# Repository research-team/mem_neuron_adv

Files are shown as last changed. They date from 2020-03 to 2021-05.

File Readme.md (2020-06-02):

Memristive neuron with selectable weights

[Link to a schematic viewer](https://www.altium.com/viewer/)

Weighted spiking neuron idea:
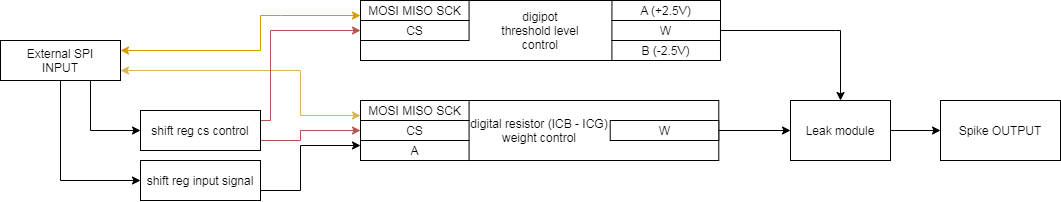
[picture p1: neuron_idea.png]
Basic idea


Last version spiking neuron schema: 
schema

Last version of spiking neuron board: 

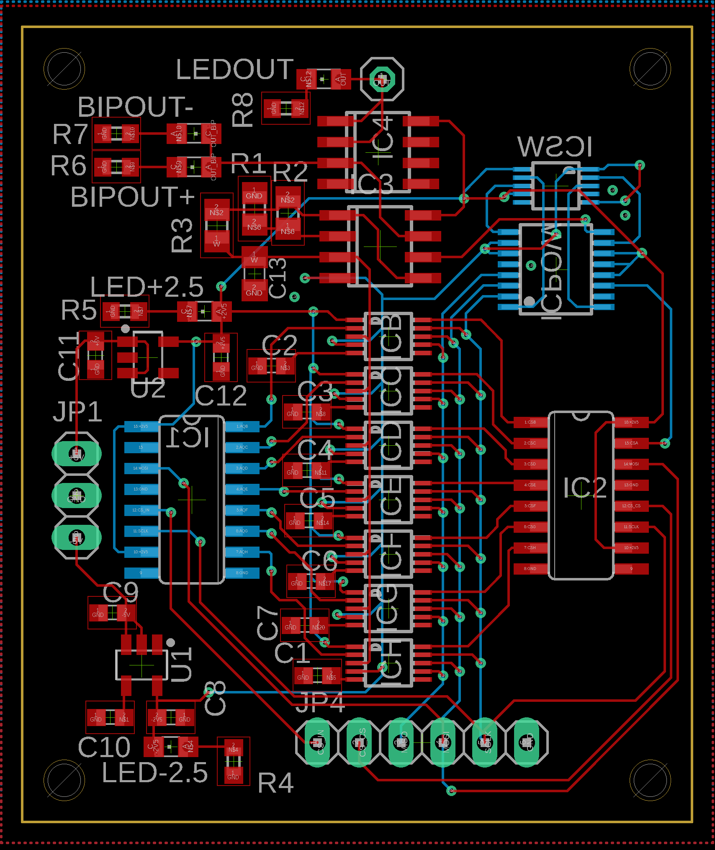
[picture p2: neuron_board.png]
board


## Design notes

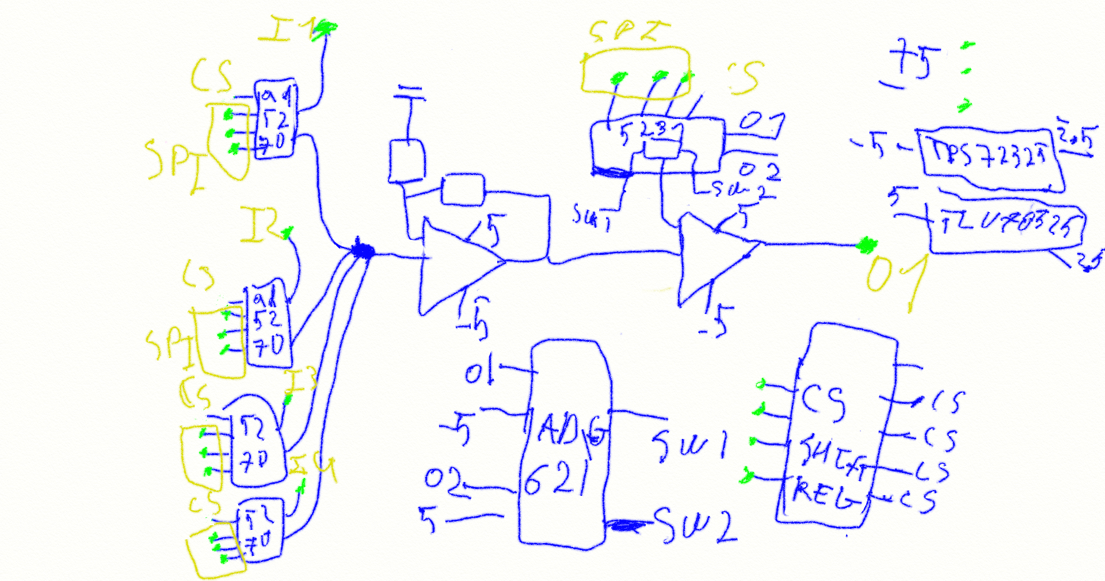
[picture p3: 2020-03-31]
neuron_idea_original.png

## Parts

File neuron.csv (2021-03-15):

Part | Value | Device | Package
C15 | 100n | C-EUC0603K | C0603K
C16 | 100n | C-EUC0603K | C0603K
C17 | 100n | C-EUC0603K | C0603K
C20 | 100n | C-EUC0603K | C0603K
C22 | 100n | C-EUC0603K | C0603K
C23 | 100n | C-EUC0603K | C0603K
C29 | 100n | C-EUC0603K | C0603K
R2 | 10K | R-EU_R0603 | R0603
R9 | 10k | R-EU_R0603 | R0603
R10 | 10k | R-EU_R0603 | R0603
R11 | 10k | R-EU_R0603 | R0603
R12 | 10k | R-EU_R0603 | R0603
R13 | 10k | R-EU_R0603 | R0603
R14 | 10k | R-EU_R0603 | R0603
R15 | 10k | R-EU_R0603 | R0603
R16 | 10k | R-EU_R0603 | R0603
R17 | 10k | R-EU_R0603 | R0603
R18 | 10k | R-EU_R0603 | R0603
R19 | 10k | R-EU_R0603 | R0603
R20 | 10k | R-EU_R0603 | R0603
R21 | 10k | R-EU_R0603 | R0603
R22 | 10k | R-EU_R0603 | R0603
R23 | 10k | R-EU_R0603 | R0603
R24 | 10k | R-EU_R0603 | R0603
R25 | 10k | R-EU_R0603 | R0603
R26 | 10k | R-EU_R0603 | R0603
R27 | 10k | R-EU_R0603 | R0603
R28 | 10k | R-EU_R0603 | R0603
R29 | 10k | R-EU_R0603 | R0603
R30 | 10k | R-EU_R0603 | R0603
R31 | 10k | R-EU_R0603 | R0603
R32 | 10k | R-EU_R0603 | R0603
R33 | 10k | R-EU_R0603 | R0603
R34 | 10k | R-EU_R0603 | R0603
R35 | 10k | R-EU_R0603 | R0603
R36 | 10k | R-EU_R0603 | R0603
R37 | 10k | R-EU_R0603 | R0603
R38 | 10k | R-EU_R0603 | R0603
R39 | 10k | R-EU_R0603 | R0603
R40 | 10k | R-EU_R0603 | R0603
R51 | 10K | R-EU_R0603 | R0603
R52 | 10K | R-EU_R0603 | R0603
C10 | 10nF | C-EUC0603 | C0603
C27 | 12.5p | C-EUC0603K | C0603K
C28 | 12.5p | C-EUC0603K | C0603K
R4 | 180R | R-EU_R0603 | R0603
R5 | 180R | R-EU_R0603 | R0603
R6 | 180R | R-EU_R0603 | R0603
R7 | 180R | R-EU_R0603 | R0603
R8 | 180R | R-EU_R0603 | R0603
R41 | 180R | R-EU_R0603 | R0603
R42 | 180R | R-EU_R0603 | R0603
R43 | 180R | R-EU_R0603 | R0603
R44 | 180R | R-EU_R0603 | R0603
R47 | 180R | R-EU_R0603 | R0603
R48 | 180R | R-EU_R0603 | R0603
R49 | 180R | R-EU_R0603 | R0603
R50 | 180R | R-EU_R0603 | R0603
C25 | 18p | C-EUC0603K | C0603K
C26 | 18p | C-EUC0603K | C0603K
R1 | 1M | R-EU_R0603 | R0603
C1 | 1uF | C-EUC0603 | C0603
C2 | 1uF | C-EUC0603 | C0603
C3 | 1uF | C-EUC0603 | C0603
C4 | 1uF | C-EUC0603 | C0603
C5 | 1uF | C-EUC0603 | C0603
C6 | 1uF | C-EUC0603 | C0603
C7 | 1uF | C-EUC0603 | C0603
C8 | 1uF | C-EUC0603 | C0603
C9 | 1uF | C-EUC0603 | C0603
C14 | 1uF | C-EUC0603 | C0603
C18 | 2.2 u | C-EUC0603K | C0603K
C19 | 2.2 u | C-EUC0603K | C0603K
C21 | 2.2 u | C-EUC0603K | C0603K
C24 | 2.2 u | C-EUC0603K | C0603K
C11 | 2uF | C-EUC0603 | C0603
C12 | 2uF | C-EUC0603 | C0603
C13 | 2uF | C-EUC0603K | C0603K
R3 | 4.7K | R-EU_R0603 | R0603
IC5 | 74HC595D | 74HC595D | SO16
X2 | 9HT10-32.768KDZF-T | 9HT10-32.768KDZF-T | 9HT10-32.768KDZF-T
X1 | ABM3B-16.000MHZ-B2-T | ABM3B-16.000MHZ-B2-T | ABM3B-16.000MHZ-B2-T
ICPOW | AD5231 | AD5231 | TSSOP16
ICA | AD5270MSOP10 | AD5270MSOP10 | MSOP10
ICB | AD5270MSOP10 | AD5270MSOP10 | MSOP10
ICC | AD5270MSOP10 | AD5270MSOP10 | MSOP10
ICD | AD5270MSOP10 | AD5270MSOP10 | MSOP10
ICE | AD5270MSOP10 | AD5270MSOP10 | MSOP10
ICF | AD5270MSOP10 | AD5270MSOP10 | MSOP10
ICG | AD5270MSOP10 | AD5270MSOP10 | MSOP10
ICH | AD5270MSOP10 | AD5270MSOP10 | MSOP10
IC1 | AD8684RU | AD8684RU | TSSOP14
IC2 | AD8684RU | AD8684RU | TSSOP14
IC3 | ADA4692-2R | ADA4692-2R | SO8
IC4 | ADA4692-2R | ADA4692-2R | SO8
ICSW | ADG621 | ADG621 | MSOP10
SW1 | B3U-1000P | B3U-1000P | B3U-1000P
P30 | JUMPER-SMT_3_NO_NO-SILK | JUMPER-SMT_3_NO_NO-SILK | SMT-JUMPER_3_NO_NO-SILK
P31 | JUMPER-SMT_3_NO_NO-SILK | JUMPER-SMT_3_NO_NO-SILK | SMT-JUMPER_3_NO_NO-SILK
P46 | JUMPER-SMT_3_NO_NO-SILK | JUMPER-SMT_3_NO_NO-SILK | SMT-JUMPER_3_NO_NO-SILK
P47 | JUMPER-SMT_3_NO_NO-SILK | JUMPER-SMT_3_NO_NO-SILK | SMT-JUMPER_3_NO_NO-SILK
PC0 | LEDCHIPLED_0805 | LEDCHIPLED_0805 | CHIPLED_0805
PC1 | LEDCHIPLED_0805 | LEDCHIPLED_0805 | CHIPLED_0805
PC2 | LEDCHIPLED_0805 | LEDCHIPLED_0805 | CHIPLED_0805
PC3 | LEDCHIPLED_0805 | LEDCHIPLED_0805 | CHIPLED_0805
URXL1 | LEDCHIPLED_0805 | LEDCHIPLED_0805 | CHIPLED_0805
URXL2 | LEDCHIPLED_0805 | LEDCHIPLED_0805 | CHIPLED_0805
UTXL1 | LEDCHIPLED_0805 | LEDCHIPLED_0805 | CHIPLED_0805
UTXL2 | LEDCHIPLED_0805 | LEDCHIPLED_0805 | CHIPLED_0805
U$1 | STM32F405RGT6 | STM32F405RG | TQFP64
U2 | TLV703 | TLV703 | SOT95P280X145-5N
U1 | TPS72301DBVRSOT-23-5 | TPS72301DBVRSOT-23-5 | SOT95P280X145-5N
BIPOUT+ |  | LEDCHIPLED_0805 | CHIPLED_0805
BIPOUT- |  | LEDCHIPLED_0805 | CHIPLED_0805
JP9 |  | PINHD-1X6 | 1X06
JP10 |  | PINHD-1X6 | 1X06
JP11 |  | PINHD-1X6 | 1X06
LED+2.5 |  | LEDCHIPLED_0805 | CHIPLED_0805
LED-2.5 |  | LEDCHIPLED_0805 | CHIPLED_0805
LEDOUT |  | LEDCHIPLED_0805 | CHIPLED_0805

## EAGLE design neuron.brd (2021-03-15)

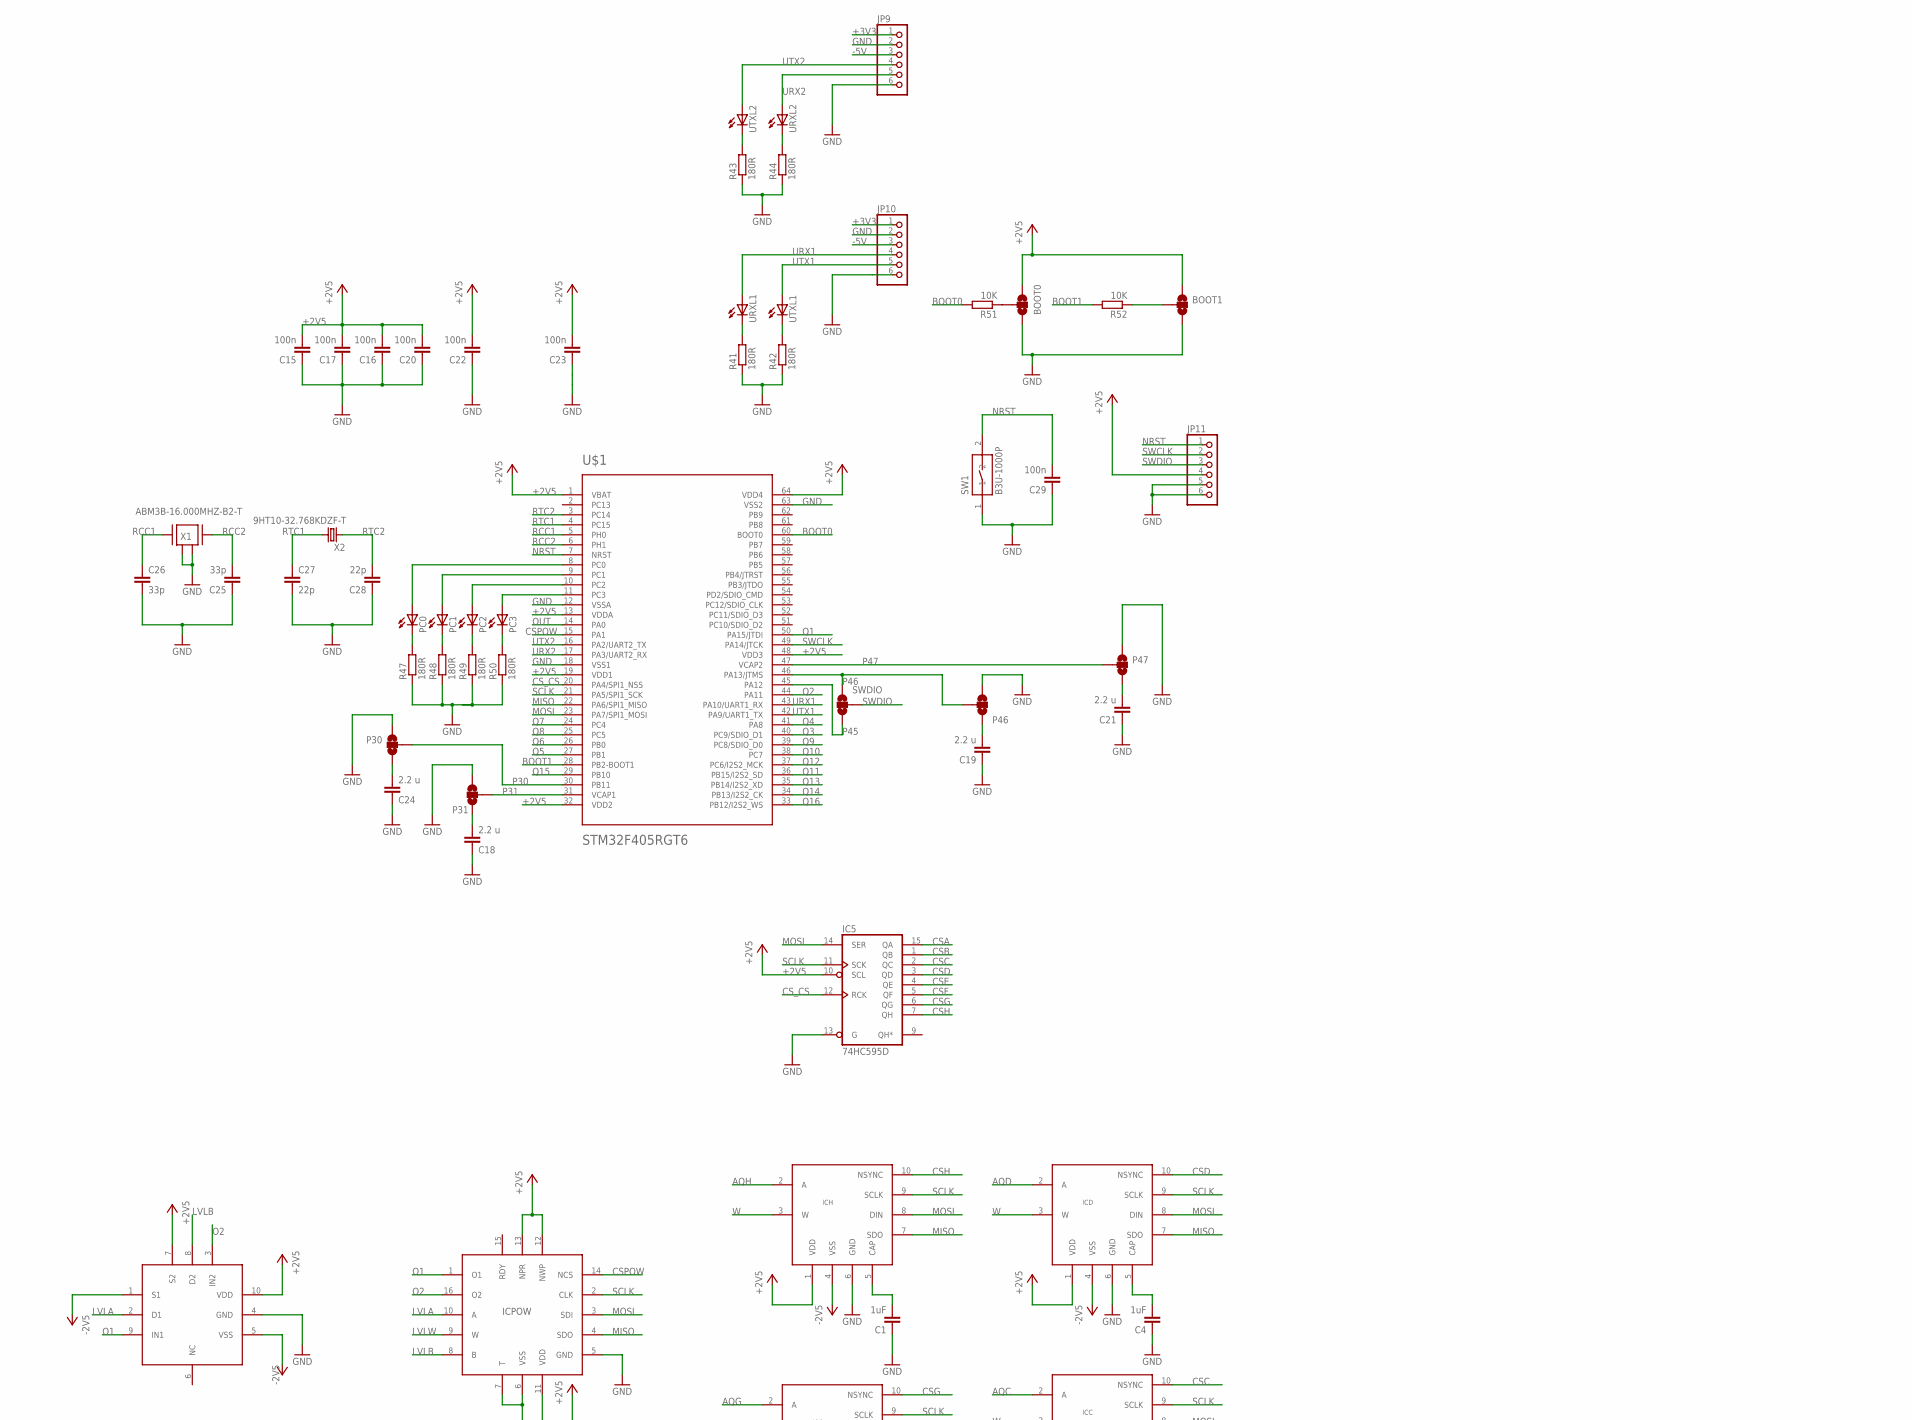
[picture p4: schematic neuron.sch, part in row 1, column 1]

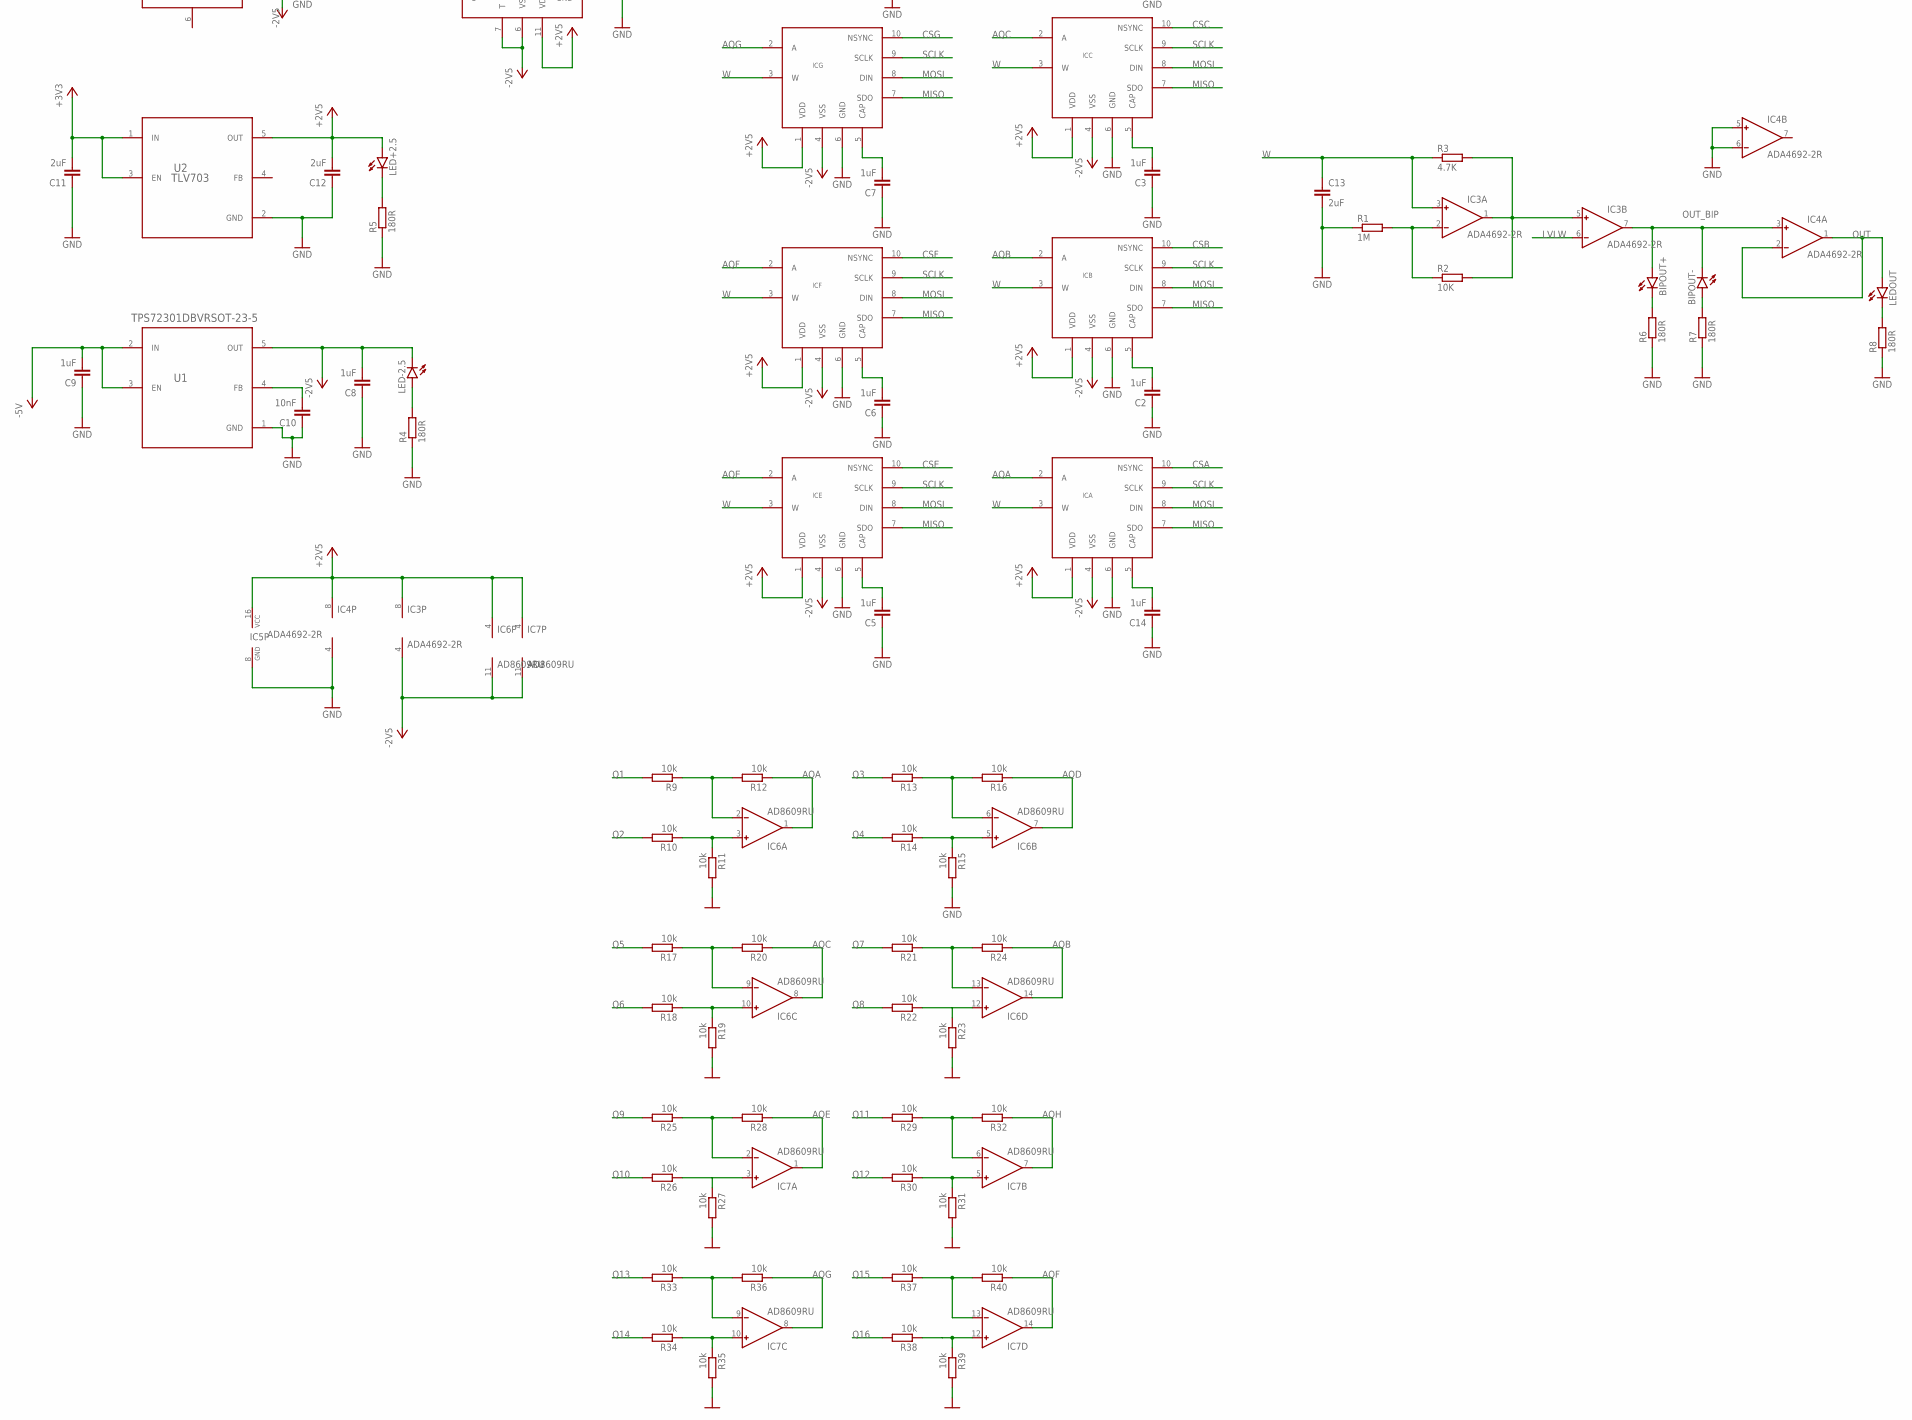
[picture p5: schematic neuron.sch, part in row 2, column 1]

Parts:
BIPOUT+: LEDCHIPLED_0805; CHIPLED_0805
BIPOUT-: LEDCHIPLED_0805; CHIPLED_0805
BOOT0, BOOT1: JUMPER-SMT_3_NO_NO-SILK; SMT-JUMPER_3_NO_NO-SILK
C1, C2, C3, C4, C5, C6, C7, C8, C9, C14: 1uF; C0603
C10: 10nF; C0603
C11, C12: 2uF; C0603
C13: 2uF; C0603K
C15, C16, C17, C20, C22, C23, C29: 100n; C0603K
C18, C19, C21, C24: 2.2 u; C0603K
C25, C26: 33p; C0603K
C27, C28: 22p; C0603K
IC3, IC4: ADA4692-2R; SO8
IC5: 74HC595D; SO16
IC6, IC7: AD8609RU; TSSOP14
ICA: AD5270MSOP10; MSOP10
ICB: AD5270MSOP10; MSOP10
ICC: AD5270MSOP10; MSOP10
ICD: AD5270MSOP10; MSOP10
ICE: AD5270MSOP10; MSOP10
ICF: AD5270MSOP10; MSOP10
ICG: AD5270MSOP10; MSOP10
ICH: AD5270MSOP10; MSOP10
ICPOW: AD5231; TSSOP16
ICSW: ADG621; MSOP10
JP9, JP10, JP11: PINHD-1X6; 1X06
LED+2.5: LEDCHIPLED_0805; CHIPLED_0805
LED-2.5: LEDCHIPLED_0805; CHIPLED_0805
LEDOUT: LEDCHIPLED_0805; CHIPLED_0805
P30, P31, P46, P47: JUMPER-SMT_3_NO_NO-SILK; SMT-JUMPER_3_NO_NO-SILK
PC0, PC1, PC2, PC3: LEDCHIPLED_0805; CHIPLED_0805
R1: 1M; R0603
R2, R51, R52: 10K; R0603
R3: 4.7K; R0603
R4, R5, R6, R7, R8, R41, R42, R43, R44, R47, R48, R49, R50: 180R; R0603
R9, R10, R11, R12, R13, R14, R15, R16, R17, R18, R19, R20, R21, R22, R23, R24, R25, R26, R27, R28, R29, R30, R31, R32, R33, R34, R35, R36, R37, R38, R39, R40: 10k; R0603
SW1: B3U-1000P
SWDIO: JUMPER-SMT_3_NO_NO-SILK; SMT-JUMPER_3_NO_NO-SILK
U1: TPS72301DBVRSOT-23-5; SOT95P280X145-5N
U2: TLV703; SOT95P280X145-5N
U$1: STM32F405RGT6; TQFP64
URXL1, URXL2: LEDCHIPLED_0805; CHIPLED_0805
UTXL1, UTXL2: LEDCHIPLED_0805; CHIPLED_0805
X1: ABM3B-16.000MHZ-B2-T
X2: 9HT10-32.768KDZF-T

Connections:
+2V5: BOOT0.1, BOOT1.1, C12.2, C15.2, C16.2, C17.2, C20.2, C22.2, C23.2, IC3.8 (V+), IC4.8 (V+), IC5.10 (SCL), IC5.16 (VCC), IC6.4 (V+), IC7.4 (V+), ICA.1 (VDD), ICB.1 (VDD), ICC.1 (VDD), ICD.1 (VDD), ICE.1 (VDD), ICF.1 (VDD), ICG.1 (VDD), ICH.1 (VDD), ICPOW.11 (VDD), ICPOW.12 (NWP), ICPOW.13 (NPR), ICSW.7 (S2), ICSW.10 (VDD), JP11.4, LED+2.5.A, U2.5 (OUT), U$1.1 (VBAT), U$1.13 (VDDA), U$1.19 (VDD1), U$1.32 (VDD2), U$1.48 (VDD3), U$1.64 (VDD4)
+3V3: C11.2, JP9.1, JP10.1, U2.1 (IN), U2.3 (EN)
-2V5: C8.2, IC3.4 (V-), IC6.11 (V-), IC7.11 (V-), ICA.4 (VSS), ICB.4 (VSS), ICC.4 (VSS), ICD.4 (VSS), ICE.4 (VSS), ICF.4 (VSS), ICG.4 (VSS), ICH.4 (VSS), ICPOW.6 (VSS), ICPOW.7 (T), ICSW.1 (S1), ICSW.5 (VSS), LED-2.5.C, U1.5 (OUT)
-5V: C9.2, JP9.3, JP10.3, U1.2 (IN), U1.3 (EN)
AQA: IC6.1 (OUT), ICA.2 (A), R12.1
AQB: IC6.14 (OUT), ICB.2 (A), R24.1
AQC: IC6.8 (OUT), ICC.2 (A), R20.1
AQD: IC6.7 (OUT), ICD.2 (A), R16.1
AQE: IC7.1 (OUT), ICE.2 (A), R28.1
AQF: IC7.14 (OUT), ICF.2 (A), R40.1
AQG: IC7.8 (OUT), ICG.2 (A), R36.1
AQH: IC7.7 (OUT), ICH.2 (A), R32.1
BOOT0: R51.2, U$1.60 (BOOT0)
BOOT1: R52.2, U$1.28 (PB2-BOOT1)
CSA: IC5.15 (QA), ICA.10 (NSYNC)
CSB: IC5.1 (QB), ICB.10 (NSYNC)
CSC: IC5.2 (QC), ICC.10 (NSYNC)
CSD: IC5.3 (QD), ICD.10 (NSYNC)
CSE: IC5.4 (QE), ICE.10 (NSYNC)
CSF: IC5.5 (QF), ICF.10 (NSYNC)
CSG: IC5.6 (QG), ICG.10 (NSYNC)
CSH: IC5.7 (QH), ICH.10 (NSYNC)
CSPOW: ICPOW.14 (NCS), U$1.15 (PA1)
CS_CS: IC5.12 (RCK), U$1.20 (PA4/SPI1_NSS)
GND: BOOT0.3, BOOT1.3, C1.1, C2.1, C3.1, C4.1, C5.1, C6.1, C7.1, C8.1, C9.1, C10.1, C11.1, C12.1, C13.2, C14.1, C15.1, C16.1, C17.1, C18.1, C19.1, C20.1, C21.1, C22.1, C23.1, C24.1, C25.1, C26.2, C27.2, C28.1, C29.1, IC4.4 (V-), IC4.5 (IN+), IC4.6 (IN-), IC5.8 (GND), IC5.13 (G), ICA.6 (GND), ICB.6 (GND), ICC.6 (GND), ICD.6 (GND), ICE.6 (GND), ICF.6 (GND), ICG.6 (GND), ICH.6 (GND), ICPOW.5 (GND), ICSW.4 (GND), JP9.2, JP9.6, JP10.2, JP10.6, JP11.5, JP11.6, P30.1, P31.1, P46.1, P47.1, R1.1, R4.1, R5.1, R6.1, R7.1, R8.1, R11.2, R15.2, R19.2, R23.2, R27.2, R31.2, R35.2, R39.2, R41.1, R42.1, R43.1, R44.1, R47.1, R48.1, R49.1, R50.1, SW1.1, U1.1 (GND), U2.2 (GND), U$1.12 (VSSA), U$1.18 (VSS1), U$1.63 (VSS2), X1.2, X1.4
LVLA: ICPOW.10 (A), ICSW.2 (D1)
LVLB: ICPOW.8 (B), ICSW.8 (D2)
LVLW: IC3.6 (IN-), ICPOW.9 (W)
MISO: ICA.7 (SDO), ICB.7 (SDO), ICC.7 (SDO), ICD.7 (SDO), ICE.7 (SDO), ICF.7 (SDO), ICG.7 (SDO), ICH.7 (SDO), ICPOW.4 (SDO), U$1.22 (PA6/SPI1_MISO)
MOSI: IC5.14 (SER), ICA.8 (DIN), ICB.8 (DIN), ICC.8 (DIN), ICD.8 (DIN), ICE.8 (DIN), ICF.8 (DIN), ICG.8 (DIN), ICH.8 (DIN), ICPOW.3 (SDI), U$1.23 (PA7/SPI1_MOSI)
unnamed: C10.2, U1.4 (FB)
unnamed: IC3.1 (OUT), IC3.5 (IN+), R2.2, R3.2
unnamed: C2.2, ICB.5 (CAP)
unnamed: LED-2.5.A, R4.2
unnamed: C1.2, ICH.5 (CAP)
unnamed: IC3.2 (IN-), R1.2, R2.1
unnamed: LED+2.5.C, R5.2
unnamed: C3.2, ICC.5 (CAP)
unnamed: BIPOUT+.C, R6.2
unnamed: BIPOUT-.A, R7.2
unnamed: C4.2, ICD.5 (CAP)
unnamed: LEDOUT.C, R8.2
unnamed: C14.2, ICA.5 (CAP)
unnamed: C5.2, ICE.5 (CAP)
unnamed: IC6.3 (IN+), R10.1, R11.1
unnamed: IC6.6 (IN-), R13.1, R16.2
unnamed: C6.2, ICF.5 (CAP)
unnamed: IC6.10 (IN+), R18.1, R19.1
unnamed: IC6.9 (IN-), R17.1, R20.2
unnamed: C7.2, ICG.5 (CAP)
unnamed: IC6.2 (IN-), R9.1, R12.2
unnamed: IC6.12 (IN+), R22.1, R23.1
unnamed: IC6.13 (IN-), R21.1, R24.2
unnamed: IC7.3 (IN+), R26.1, R27.1
unnamed: IC7.12 (IN+), R38.1, R39.1
unnamed: IC6.5 (IN+), R14.1, R15.1
unnamed: IC7.6 (IN-), R29.1, R32.2
unnamed: IC7.10 (IN+), R34.1, R35.1
unnamed: IC7.9 (IN-), R33.1, R36.2
unnamed: BOOT0.2, R51.1
unnamed: IC7.13 (IN-), R37.1, R40.2
unnamed: IC7.5 (IN+), R30.1, R31.1
unnamed: R43.2, UTXL2.C
unnamed: R44.2, URXL2.C
unnamed: C21.2, P47.3
unnamed: C18.2, P31.3
unnamed: R41.2, URXL1.C
unnamed: R42.2, UTXL1.C
unnamed: IC7.2 (IN-), R25.1, R28.2
unnamed: PC0.C, R47.2
unnamed: PC1.C, R48.2
unnamed: PC2.C, R49.2
unnamed: PC3.C, R50.2
unnamed: C19.2, P46.3
unnamed: BOOT1.2, R52.1
unnamed: C24.2, P30.3
unnamed: PC3.A, U$1.11 (PC3)
unnamed: PC2.A, U$1.10 (PC2)
unnamed: PC1.A, U$1.9 (PC1)
unnamed: PC0.A, U$1.8 (PC0)
NRST: C29.2, JP11.1, SW1.2, U$1.7 (NRST)
O1: ICPOW.1 (O1), ICSW.9 (IN1)
O2: ICPOW.16 (O2), ICSW.3 (IN2)
OUT: IC4.1 (OUT), IC4.2 (IN-), LEDOUT.A, U$1.14 (PA0)
OUT_BIP: BIPOUT+.A, BIPOUT-.C, IC3.7 (OUT), IC4.3 (IN+)
P30: P30.2, U$1.30 (PB11)
P31: P31.2, U$1.31 (VCAP1)
P45: SWDIO.1, U$1.45 (PA12)
P46: P46.2, SWDIO.3, U$1.46 (PA13/JTMS)
P47: P47.2, U$1.47 (VCAP2)
Q1: R9.2, U$1.50 (PA15/JTDI)
Q2: R10.2, U$1.44 (PA11)
Q3: R13.2, U$1.40 (PC9/SDIO_D1)
Q4: R14.2, U$1.41 (PA8)
Q5: R17.2, U$1.27 (PB1)
Q6: R18.2, U$1.26 (PB0)
Q7: R21.2, U$1.24 (PC4)
Q8: R22.2, U$1.25 (PC5)
Q9: R25.2, U$1.39 (PC8/SDIO_D0)
Q10: R26.2, U$1.38 (PC7)
Q11: R29.2, U$1.36 (PB15/I2S2_SD)
Q12: R30.2, U$1.37 (PC6/I2S2_MCK)
Q13: R33.2, U$1.35 (PB14/I2S2_XD)
Q14: R34.2, U$1.34 (PB13/I2S2_CK)
Q15: R37.2, U$1.29 (PB10)
Q16: R38.2, U$1.33 (PB12/I2S2_WS)
RCC1: C26.1, U$1.5 (PH0), X1.1
RCC2: C25.2, U$1.6 (PH1), X1.3
RTC1: C27.1, U$1.4 (PC15), X2.2
RTC2: C28.2, U$1.3 (PC14), X2.1
SCLK: IC5.11 (SCK), ICA.9 (SCLK), ICB.9 (SCLK), ICC.9 (SCLK), ICD.9 (SCLK), ICE.9 (SCLK), ICF.9 (SCLK), ICG.9 (SCLK), ICH.9 (SCLK), ICPOW.2 (CLK), U$1.21 (PA5/SPI1_SCK)
SWCLK: JP11.2, U$1.49 (PA14/JTCK)
SWDIO: JP11.3, SWDIO.2
URX1: JP10.4, U$1.43 (PA10/UART1_RX), URXL1.A
URX2: JP9.5, U$1.17 (PA3/UART2_RX), URXL2.A
UTX1: JP10.5, U$1.42 (PA9/UART1_TX), UTXL1.A
UTX2: JP9.4, U$1.16 (PA2/UART2_TX), UTXL2.A
W: C13.1, IC3.3 (IN+), ICA.3 (W), ICB.3 (W), ICC.3 (W), ICD.3 (W), ICE.3 (W), ICF.3 (W), ICG.3 (W), ICH.3 (W), R3.1

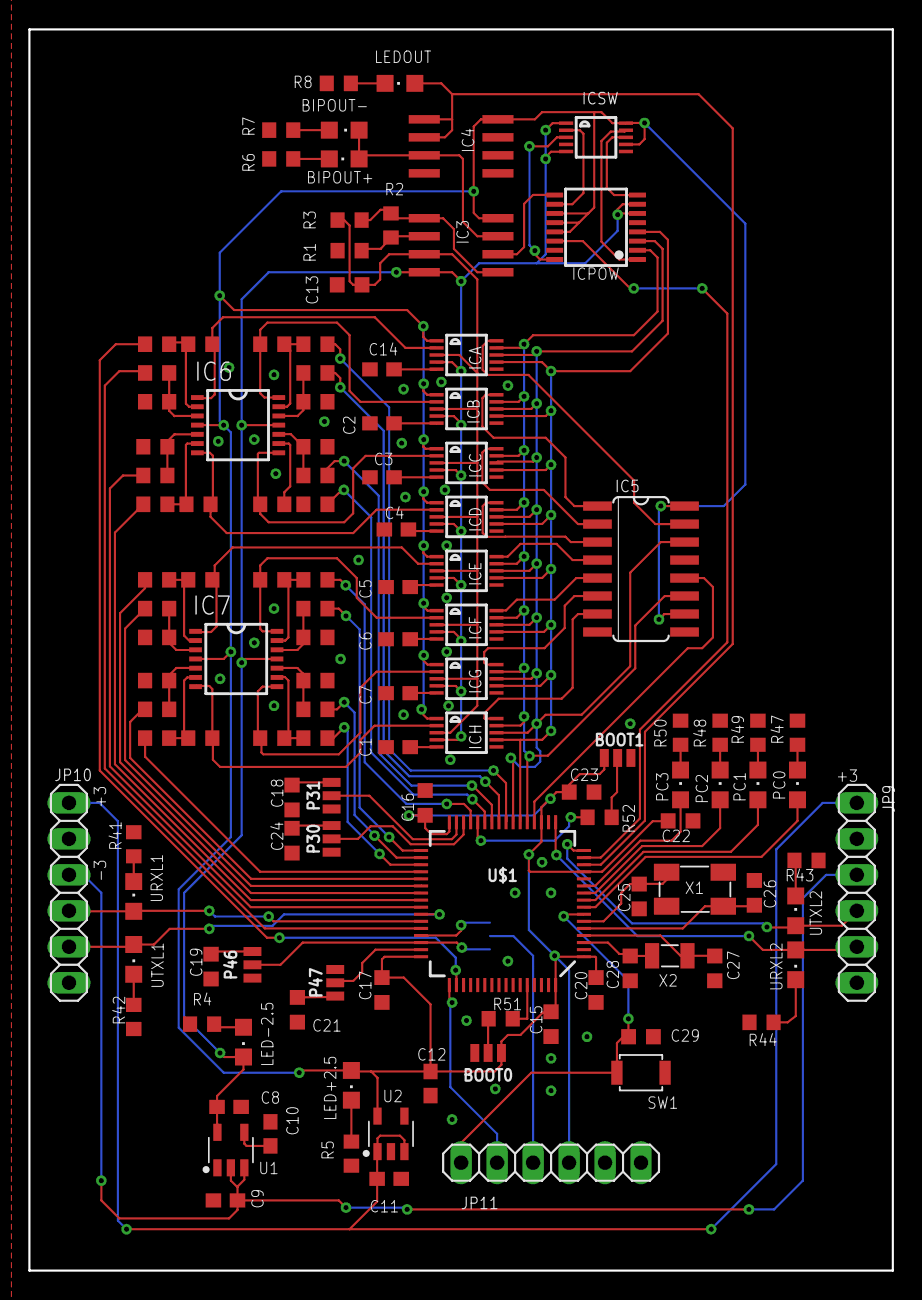
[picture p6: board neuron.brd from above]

Board: 2 copper layers, 61.0 x 87.6 mm, 123 parts (1 on the bottom side), 118 nets.

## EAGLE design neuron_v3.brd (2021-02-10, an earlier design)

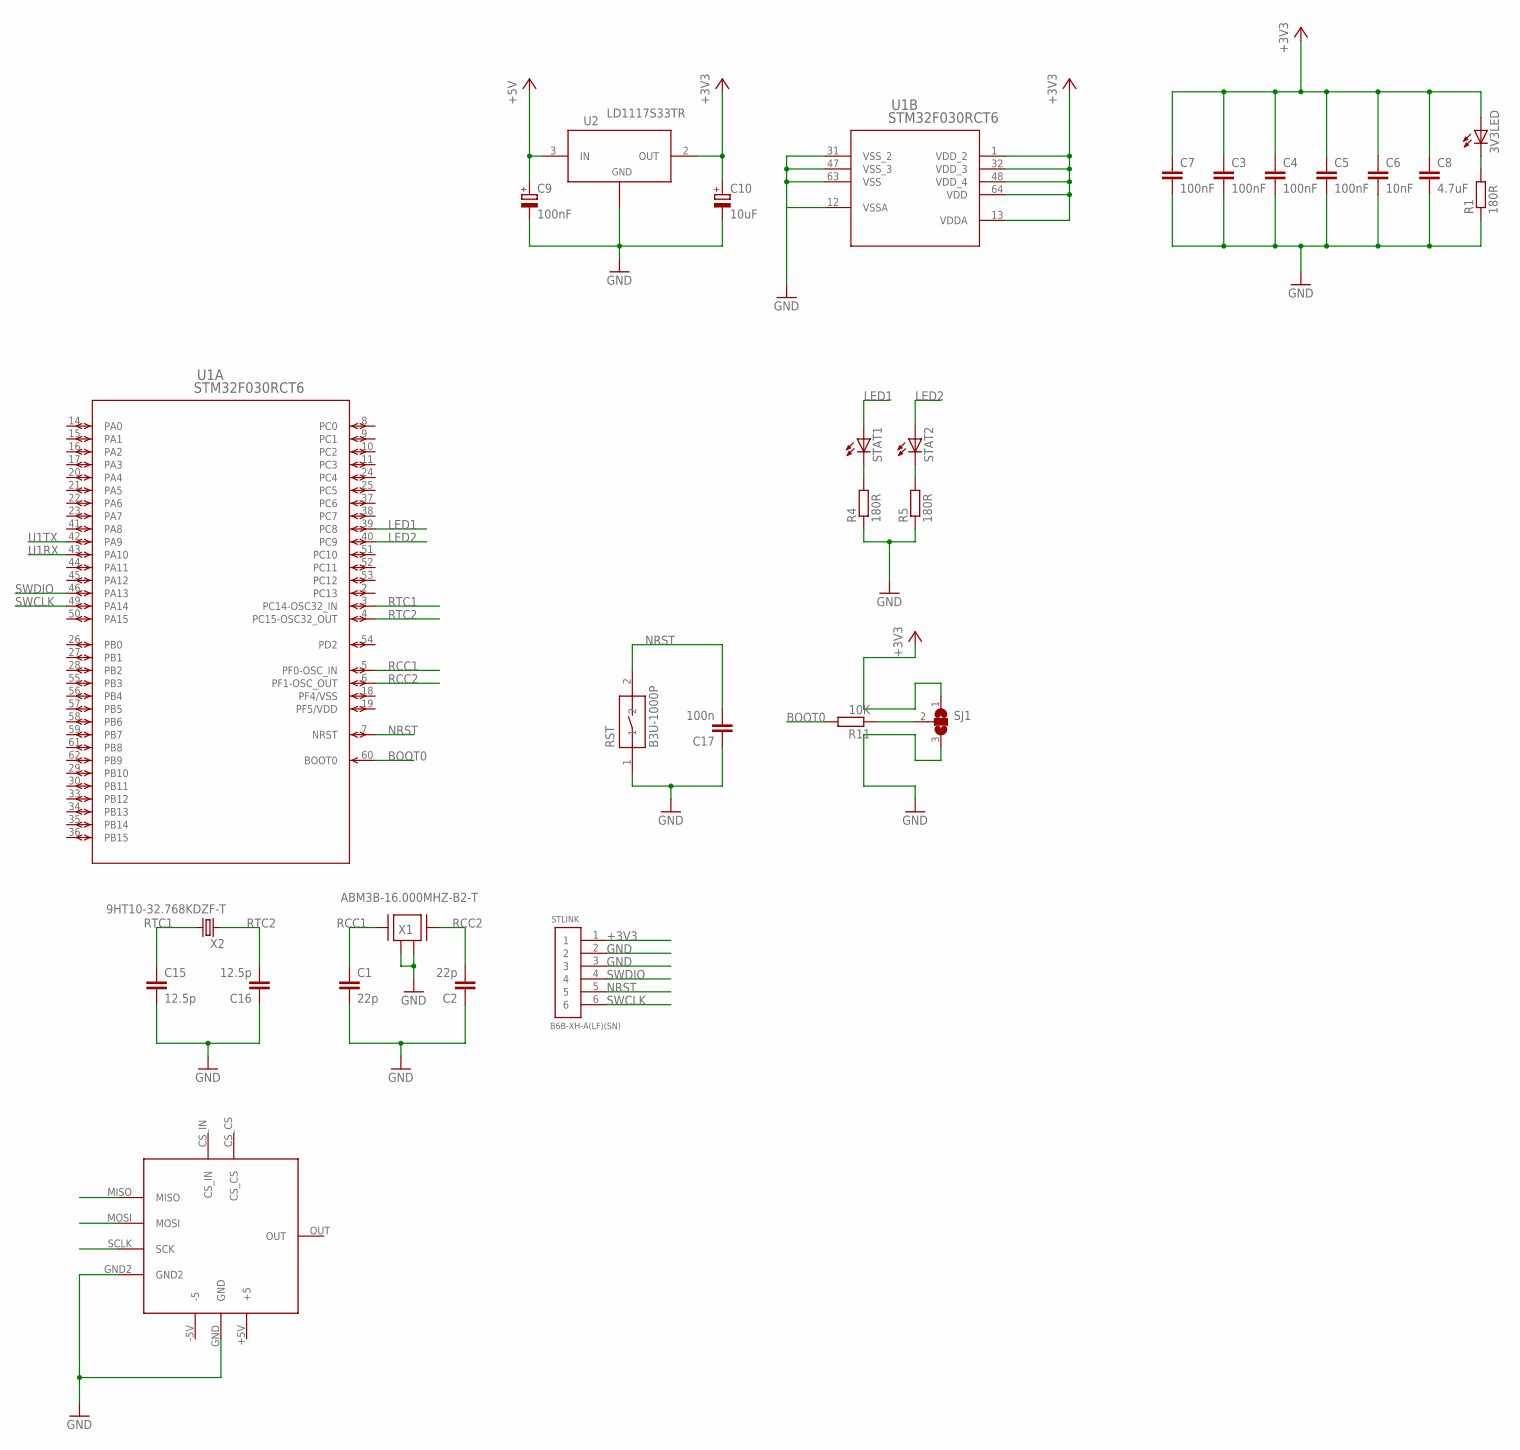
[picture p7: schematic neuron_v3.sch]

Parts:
3V3LED: LEDCHIPLED_0805; CHIPLED_0805
C1, C2: 22p; C0603K
C3, C4, C5, C7: 100nF; C0603K
C6: 10nF; C0603K
C8: 4.7uF; C0603K
C9: 100nF; A/3216-18W
C10: 10uF; A/3216-18W
C15, C16: 12.5p; C0603K
C17: 100n; C0603K
R1, R4, R5: 180R; R0603
R11: 10K; R0603
RST: B3U-1000P
SJ1: SJ2W; SJ_2
STAT1, STAT2: LEDCHIPLED_0805; CHIPLED_0805
STLINK: B6B-XH-A(LF)(SN)
U1: STM32F030RCT6; LQFP64-10X10MM
U2: LD1117S33TR; SOT-223
U$1: NEURON_BOARD
X1: ABM3B-16.000MHZ-B2-T
X2: 9HT10-32.768KDZF-T

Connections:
+3V3: 3V3LED.A, C3.1, C4.1, C5.1, C6.1, C7.1, C8.1, C10.+, SJ1.1, STLINK.1, U1.1 (VDD_2), U1.13 (VDDA), U1.32 (VDD_3), U1.48 (VDD_4), U1.64 (VDD), U2.2 (OUT), U2.4
+5V: C9.+, U2.3 (IN)
BOOT0: R11.2, U1.60 (BOOT0)
GND: C1.2, C2.1, C3.2, C4.2, C5.2, C6.2, C7.2, C8.2, C9.-, C10.-, C15.2, C16.1, C17.1, R1.1, R4.1, R5.1, RST.1, SJ1.3, STLINK.2, STLINK.3, U1.12 (VSSA), U1.31 (VSS_2), U1.47 (VSS_3), U1.63 (VSS), U2.1 (ADJ/GND), U$1.GND, U$1.GND2, X1.2, X1.4
LED1: STAT1.A, U1.39 (PC8)
LED2: STAT2.A, U1.40 (PC9)
unnamed: 3V3LED.C, R1.2
unnamed: R4.2, STAT1.C
unnamed: R5.2, STAT2.C
unnamed: R11.1, SJ1.2
NRST: C17.2, RST.2, STLINK.5, U1.7 (NRST)
RCC1: C1.1, U1.5 (PF0-OSC_IN), X1.1
RCC2: C2.2, U1.6 (PF1-OSC_OUT), X1.3
RTC1: C15.1, U1.3 (PC14-OSC32_IN), X2.2
RTC2: C16.2, U1.4 (PC15-OSC32_OUT), X2.1
SWCLK: STLINK.6, U1.49 (PA14)
SWDIO: STLINK.4, U1.46 (PA13)
U1RX: U1.43 (PA10)
U1TX: U1.42 (PA9)

Board: 2 copper layers, 28 parts (0 on the bottom side), 17 nets, no tracks yet.

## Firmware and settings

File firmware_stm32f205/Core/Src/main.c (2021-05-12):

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
/* Includes ------------------------------------------------------------------*/
#include "main.h"

/* USER CODE BEGIN Includes */
#include <time.h>
#include <string.h>
/* USER CODE END Includes */

RTC_HandleTypeDef hrtc;

SPI_HandleTypeDef hspi1;
SPI_HandleTypeDef hspi3;

TIM_HandleTypeDef htim1;

UART_HandleTypeDef huart1;
UART_HandleTypeDef huart2;

/* USER CODE BEGIN PV */
uint8_t flags=0;
//total boards in chain
uint8_t board_cnt=3;
//current board number
uint8_t board_num=0;
//last spike time
int32_t last_spike=0;
//width of spike storage
uint8_t spike_wid=0;
uint8_t spike_wid_rst=0;
//if channel is excitatory
//bitwise info - all channels are excitatory
uint8_t ex_channels = 0x1F;
//GPIO info for each channel;
//signal level is Apin-Bpin
uint16_t Apin[8]={Q2_Pin,Q4_Pin,Q6_Pin,Q8_Pin,Q10_Pin,Q12_Pin,Q14_Pin,Q16_Pin};
uint16_t Bpin[8]={Q1_Pin,Q3_Pin,Q5_Pin,Q7_Pin,Q9_Pin,Q11_Pin,Q13_Pin,Q15_Pin};
GPIO_TypeDef* Aport[8]={Q2_GPIO_Port,Q4_GPIO_Port,Q6_GPIO_Port,Q8_GPIO_Port,Q10_GPIO_Port,Q12_GPIO_Port,Q14_GPIO_Port,Q16_GPIO_Port};
GPIO_TypeDef* Bport[8]={Q1_GPIO_Port,Q3_GPIO_Port,Q5_GPIO_Port,Q7_GPIO_Port,Q9_GPIO_Port,Q11_GPIO_Port,Q13_GPIO_Port,Q15_GPIO_Port};
//weight collection
int32_t last_spike_time[8]={0,0,0,0,0,0,0,0};
uint16_t weights[8]={100,200,400,400,500,700,800,900};
//uint16_t weights[8]={100,200,200,200,200,700,800,900};
/* USER CODE END PV */

void SystemClock_Config(void);
static void MX_GPIO_Init(void);
static void MX_RTC_Init(void);
static void MX_SPI1_Init(void);
static void MX_USART1_UART_Init(void);
static void MX_USART2_UART_Init(void);
static void MX_SPI3_Init(void);
static void MX_TIM1_Init(void);
/* USER CODE BEGIN PFP */
void HAL_GPIO_EXTI_Callback(uint16_t GPIO_Pin)
{
  if(GPIO_Pin== GPIO_PIN_0) {
	  SET_BITN(flags,0);
  }
}
void HAL_UART_RxCpltCallback(UART_HandleTypeDef *huart){
	SET_BITN(flags,2);
}
void set_cmd(uint8_t num,uint8_t cmd,uint16_t val){
	uint8_t cs_data[1];
	cs_data[0]=~(1<<num);

	uint8_t res_data_rx[2];
	uint8_t res_data_tx[2];

	//read datasheet carefully
	//00 0001 00000 00000
	//0000 0100 0000 0000
	res_data_tx[0]=(cmd<<2)|(val>>8);
	res_data_tx[1]=val&0XFF;

	HAL_GPIO_WritePin(CS_CS_GPIO_Port, CS_CS_Pin, GPIO_PIN_RESET);
	HAL_SPI_Transmit(&hspi3, cs_data, 1, 1000);
	HAL_GPIO_WritePin(CS_CS_GPIO_Port, CS_CS_Pin, GPIO_PIN_SET);

	HAL_SPI_TransmitReceive(&hspi1, res_data_tx,res_data_rx, 2, 1000);

	cs_data[0]=0xFF;
	HAL_GPIO_WritePin(CS_CS_GPIO_Port, CS_CS_Pin, GPIO_PIN_RESET);
	HAL_SPI_Transmit(&hspi3, cs_data, 1, 1000);
	HAL_GPIO_WritePin(CS_CS_GPIO_Port, CS_CS_Pin, GPIO_PIN_SET);
}
void set_res(uint8_t num,uint16_t val){
	set_cmd(num,1,val);
}
void Hebb_weight_update(uint8_t last_spiked){
	//do some wired math
	//TODO:remake weight
	//use last spike times to do some magic
	uint8_t i=0;
	for(i=0;i<8;i++){
		weights[i]+=last_spike_time[i];
		if (weights[i]>0x03FF){
			weights[i]=0x03FF;
		}
	}
	uint8_t ls_tmp=last_spiked;
	i=0;
	while(ls_tmp>0){
		//if this input spiked
		if((ls_tmp&0x01)==1){
			//CS for resistor
			set_res(i,weights[i]);
		}
		else{
			last_spike_time[i]+=last_spike;
			//no need for big times since hebb will be zero anyways
			if(last_spike_time[i]>10000){
				last_spike_time[i]=10000;
			}
		}
		ls_tmp>>=1;
		i++;
	}

}
/* USER CODE END PFP */

/**
  * @brief  The application entry point.
  * @retval int
  */
int main(void)
{
  /* MCU Configuration--------------------------------------------------------*/

  /* Reset of all peripherals, Initializes the Flash interface and the Systick. */
  HAL_Init();

  /* Configure the system clock */
  SystemClock_Config();

  /* Initialize all configured peripherals */
  MX_GPIO_Init();
  MX_RTC_Init();
  MX_SPI1_Init();
  MX_USART1_UART_Init();
  MX_USART2_UART_Init();
  MX_SPI3_Init();
  MX_TIM1_Init();
  /* USER CODE BEGIN 2 */
  HAL_Delay(1000);
  /* USER CODE END 2 */

  /* Infinite loop */
  /* USER CODE BEGIN WHILE */

  //enable O1 and O2
  //0011 0001 0000 0000 0000 0000
  uint8_t data1[3]={0x31,0x00,0x03};
  uint8_t data2[3];
//  HAL_GPIO_WritePin(CSPOW_GPIO_Port, CSPOW_Pin, GPIO_PIN_RESET);
//  HAL_SPI_TransmitReceive(&hspi1, data1,data2, 3, 1000);
//  HAL_GPIO_WritePin(CSPOW_GPIO_Port, CSPOW_Pin, GPIO_PIN_SET);
//  HAL_Delay(1);

  //set trigger level once, never touch again and change mode for weight update
  data1[0]=0xB0;
  data1[1]=0x01;
  data1[2]=0xA0;
  HAL_GPIO_WritePin(CSPOW_GPIO_Port, CSPOW_Pin, GPIO_PIN_RESET);
  HAL_SPI_TransmitReceive(&hspi1, data1,data2, 3, 1000);
  HAL_GPIO_WritePin(CSPOW_GPIO_Port, CSPOW_Pin, GPIO_PIN_SET);
  //change mode for resistor
  hspi1.Init.CLKPhase = SPI_PHASE_2EDGE;
  if (HAL_SPI_Init(&hspi1) != HAL_OK){
	  Error_Handler();
  }

  uint8_t i=0;

  for(i=0;i<8;i++){
	  set_cmd(i, 7, 2);
  	  set_res(i,weights[i]);
  }
//  for(i=1;i<8;i++){
//	  set_res(1,10);
//    }
//  for(i=2;i<8;i++){
//  	  set_res(i,200);
//      }

  HAL_GPIO_WritePin(GPIOC, LED1_Pin|LED2_Pin|LED3_Pin|LED4_Pin, GPIO_PIN_RESET);

  HAL_TIM_Base_Start_IT(&htim1);
  uint8_t rx_data[board_cnt];
  uint8_t tx_data[board_cnt];
  uint8_t data_tmp=0;
  uint8_t ext_info_tmp=0;
  for(i=0;i<board_cnt;i++){
	  tx_data[i]=0;
	  rx_data[i]=0;
  }
//  if (board_num==0){
//	  tx_data[0]=0x55;
//	  tx_data[1]=0xAA;
//	  tx_data[2]=0xF5;
//  	  HAL_UART_Transmit_DMA(&huart2, tx_data, board_cnt);
//  }
  uint16_t delay=201;
  HAL_StatusTypeDef status;
  while (1)
  {
//	  HAL_GPIO_TogglePin(GPIOC, LED1_Pin);
	  status=HAL_UART_Receive(&huart1,  rx_data, board_cnt,10000);
	  if(status!=HAL_TIMEOUT){
		  HAL_GPIO_TogglePin(GPIOC, LED4_Pin);
		  data_tmp=rx_data[board_num];
		  //copy info about input types
		  ext_info_tmp=ex_channels;
		  i=0;
		  while(data_tmp>0){
			  if((data_tmp&0x01)==1){
				  if((ext_info_tmp&0x01)==1){
					  //if is exitatory pull down b port
					  HAL_GPIO_WritePin(Bport[i], Bpin[i], GPIO_PIN_RESET);
				  }
				  else{
//					  if is inhibitory pull down a port
					  HAL_GPIO_WritePin(Aport[i], Apin[i], GPIO_PIN_RESET);
				  }
				  spike_wid=0;
				  spike_wid_rst=1;
			  }
			  i++;
			  ext_info_tmp>>=1;
			  data_tmp>>=1;
		  }

		  while(spike_wid<30){}
		  for(i=0;i<8;i++){
			  HAL_GPIO_WritePin(Aport[i], Apin[i], GPIO_PIN_SET);
			  HAL_GPIO_WritePin(Bport[i], Bpin[i], GPIO_PIN_SET);
		  }
//		  output signal generated
		  if(READ_BITN(flags,0)==1){
			  RESET_BITN(flags,0);
			  HAL_GPIO_TogglePin(GPIOC, LED2_Pin);
//			  need to update weight according to wired math and what spiked last time
//			  Hebb_weight_update(rx_data[board_num]);
			  tx_data[0]=0;
			  tx_data[1]=rx_data[0];
			  tx_data[2]=rx_data[2];
//			  tx_data[2]=(rx_data[2]<<1)|1;
			  i=0;
			  data_tmp=rx_data[board_num];
			  while(data_tmp>0){
				  if((data_tmp&0x01)==1){
					  if(weights[i]>5){
						  weights[i]-=5;
					  }
					  set_res(i,weights[i]);
				  }
				  i++;
				  data_tmp>>=1;
			  }
//			  for(i=0;i<5;i++){
//				  weights[i]+=100;
////				  weights[i]+=i;
//				  if (weights[i]>1023){
//					  weights[i]=1023;
//				  }
//				  set_res(i,weights[i]);
//			  }
			  //change last spike time to negative value for emulating refactory period
			  last_spike=-100;
			  if (delay>10){
				  delay-=10;
			  }
		  }
		  else{
			  tx_data[0]=0;
			  tx_data[1]=rx_data[0];
			  tx_data[2]=rx_data[2];
			  if (delay<10000){
				  delay+=10;
			  }
		  }
		  HAL_Delay(delay);
		  HAL_UART_Transmit(&huart2, tx_data, board_cnt,1000);
		  for(i=0;i<board_cnt;i++){
			  tx_data[i]=0;
			  rx_data[i]=0;
		  }
	  }
    /* USER CODE END WHILE */

    /* USER CODE BEGIN 3 */
  }
  /* USER CODE END 3 */
}

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
 /**
  * @brief  Period elapsed callback in non blocking mode
  * @note   This function is called  when TIM14 interrupt took place, inside
  * HAL_TIM_IRQHandler(). It makes a direct call to HAL_IncTick() to increment
  * a global variable "uwTick" used as application time base.
  * @param  htim : TIM handle
  * @retval None
  */
void HAL_TIM_PeriodElapsedCallback(TIM_HandleTypeDef *htim)
{
  if (htim->Instance == TIM14) {
    HAL_IncTick();
  }
  /* USER CODE BEGIN Callback 1 */
  else if (htim->Instance == TIM1) {
	  last_spike+=1;
	  spike_wid+=1;
	  if(spike_wid_rst==1){
		  spike_wid_rst=0;
		  spike_wid=0;
	  }
    }
  /* USER CODE END Callback 1 */
}

/**
  * @brief  This function is executed in case of error occurrence.
  * @retval None
  */
void Error_Handler(void)
{
  /* USER CODE BEGIN Error_Handler_Debug */
  /* User can add his own implementation to report the HAL error return state */
  __disable_irq();
  while (1)
  {
  }
  /* USER CODE END Error_Handler_Debug */
}

#ifdef  USE_FULL_ASSERT
/**
  * @brief  Reports the name of the source file and the source line number
  *         where the assert_param error has occurred.
  * @param  file: pointer to the source file name
  * @param  line: assert_param error line source number
  * @retval None
  */
void assert_failed(uint8_t *file, uint32_t line)
{
  /* USER CODE BEGIN 6 */
  /* User can add his own implementation to report the file name and line number,
     ex: printf("Wrong parameters value: file %s on line %d\r\n", file, line) */
  /* USER CODE END 6 */
}
#endif /* USE_FULL_ASSERT */

/************************ (C) COPYRIGHT STMicroelectronics *****END OF FILE****/

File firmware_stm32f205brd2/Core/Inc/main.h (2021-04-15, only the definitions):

#define LED1_Pin GPIO_PIN_0
#define LED1_GPIO_Port GPIOC
#define LED2_Pin GPIO_PIN_1
#define LED2_GPIO_Port GPIOC
#define LED3_Pin GPIO_PIN_2
#define LED3_GPIO_Port GPIOC
#define LED4_Pin GPIO_PIN_3
#define LED4_GPIO_Port GPIOC
#define OUT_Pin GPIO_PIN_0
#define OUT_GPIO_Port GPIOA
#define OUT_EXTI_IRQn EXTI0_IRQn
#define CSPOW_Pin GPIO_PIN_1
#define CSPOW_GPIO_Port GPIOA
#define CS_CS_Pin GPIO_PIN_4
#define CS_CS_GPIO_Port GPIOA
#define Q7_Pin GPIO_PIN_4
#define Q7_GPIO_Port GPIOC
#define Q8_Pin GPIO_PIN_5
#define Q8_GPIO_Port GPIOC
#define Q6_Pin GPIO_PIN_0
#define Q6_GPIO_Port GPIOB
#define Q5_Pin GPIO_PIN_1
#define Q5_GPIO_Port GPIOB
#define Q15_Pin GPIO_PIN_10
#define Q15_GPIO_Port GPIOB
#define Q16_Pin GPIO_PIN_12
#define Q16_GPIO_Port GPIOB
#define Q14_Pin GPIO_PIN_13
#define Q14_GPIO_Port GPIOB
#define Q13_Pin GPIO_PIN_14
#define Q13_GPIO_Port GPIOB
#define Q11_Pin GPIO_PIN_15
#define Q11_GPIO_Port GPIOB
#define Q12_Pin GPIO_PIN_6
#define Q12_GPIO_Port GPIOC
#define Q10_Pin GPIO_PIN_7
#define Q10_GPIO_Port GPIOC
#define Q9_Pin GPIO_PIN_8
#define Q9_GPIO_Port GPIOC
#define Q3_Pin GPIO_PIN_9
#define Q3_GPIO_Port GPIOC
#define Q4_Pin GPIO_PIN_8
#define Q4_GPIO_Port GPIOA
#define Q2_Pin GPIO_PIN_11
#define Q2_GPIO_Port GPIOA
#define Q1_Pin GPIO_PIN_15
#define Q1_GPIO_Port GPIOA

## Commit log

2020-03-20 few more connections
    [leak.brd, leak.sch]
2020-03-31 added link to a viewer and op amp
    [leak.brd, leak.sch]
2020-03-31 finished schematic
    [leak.brd, leak.sch]
2020-04-01 started pcb layout
    [leak.brd, leak.sch]
2020-04-07 v1 finished
    [leak.brd, leak.sch]
2020-04-08 modified filenames to match reality
    [neuron.brd, neuron.sch]
2020-04-08 modified board picture
2020-04-08 added some measurements
    [neuron.brd]
2020-04-08 added basics for OM board
    [OM.brd, OM.sch]
2020-06-02 added new version with controller
    [bipolar_inp.brd, bipolar_inp.sch, neuron.brd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]
2020-06-09 Almost finished neuron v2
    [neuron.brd, neuron.sch]
2021-02-10 finished v1
    [OM.brd, OM.sch, neuron.brd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]
2021-02-10 some patches
    [neuron.brd, neuron.sch]
2021-02-10 last push to a360
    [neuron.brd]
2021-03-15 added firmware
    [neuron.brd, neuron.csv, neuron.sch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]
2021-03-31 added some uart tests
    [mem_neuro_adv_stm32f205OCD.cfg]
2021-04-02 added uart parser
2021-04-15 multiple boards test
2021-04-21 added multiple firmwares
    [mem_neuro_adv_stm32f205OCD.cfg]
2021-04-27 weight resistors fixed

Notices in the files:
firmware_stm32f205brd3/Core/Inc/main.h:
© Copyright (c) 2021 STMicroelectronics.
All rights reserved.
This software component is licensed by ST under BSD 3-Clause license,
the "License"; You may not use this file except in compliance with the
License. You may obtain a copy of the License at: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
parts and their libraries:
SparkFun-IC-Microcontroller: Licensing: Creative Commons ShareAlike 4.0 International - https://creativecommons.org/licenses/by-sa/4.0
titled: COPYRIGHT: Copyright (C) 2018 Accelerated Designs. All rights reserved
